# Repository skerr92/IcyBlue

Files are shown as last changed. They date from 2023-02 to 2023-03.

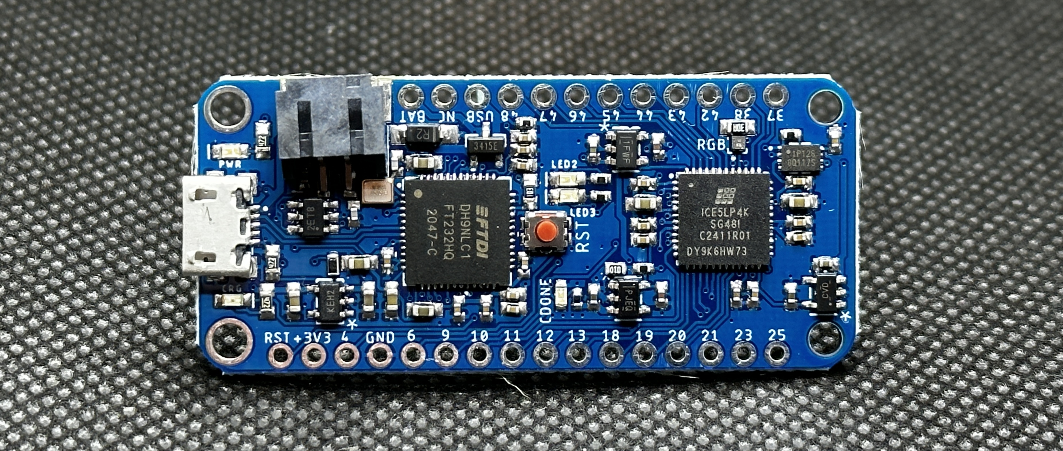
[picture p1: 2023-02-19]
Images/IMG_0353.jpg

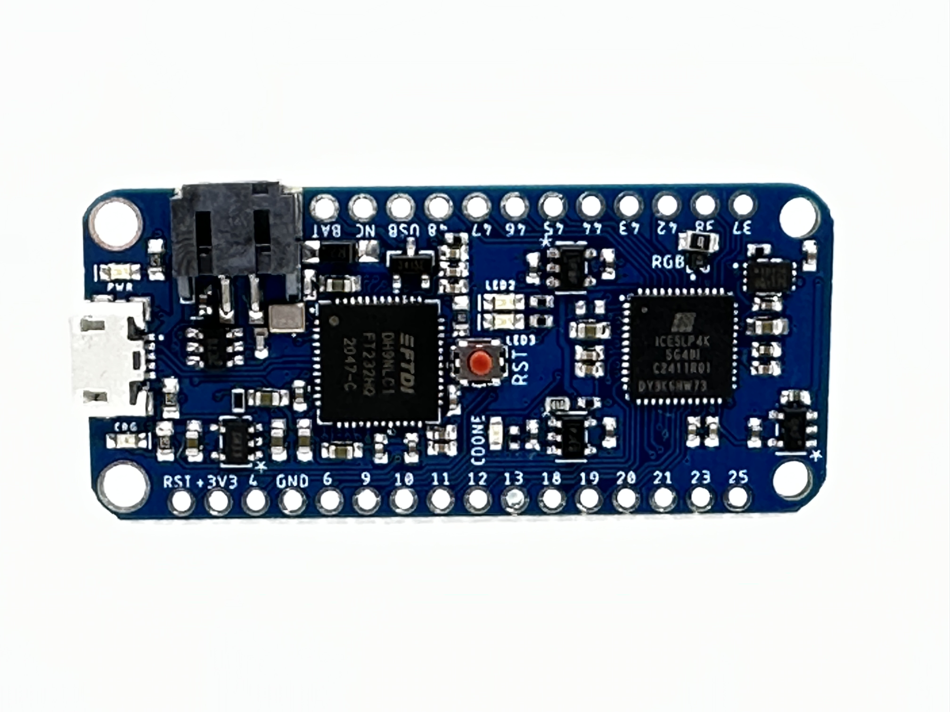
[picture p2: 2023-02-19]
Images/IMG_0367.JPG

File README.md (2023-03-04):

# IcyBlue Feather FPGA Development Board

<image src="https://github.com/skerr92/IcyBlue/blob/main/Images/IMG_0353.jpg">

Welcome to the home of the IcyBlue Feather, an FPGA based development board designed to be integrated into the Adafruit Feather ecosystem of Feathers and Feather Wings.

The goal of this repository is to be the single source of truth for the IcyBlue Feather. Containing all the relevant articles including images, schematics, usage examples, board files, and other important documentation.

Questions? Email [hello@oakdev.tech](mailto:hello@oakdev.tech)

### Documentation ###

All documentation can be found under the [Documentation](https://github.com/skerr92/IcyBlue/tree/main/Documentation) directory of this repository. This will include data sheets, usage guides, application notes, errata, and other important documents.

Documentation quick links:
* Data sheet: [IcyBlue Overview Data Sheet](https://github.com/skerr92/IcyBlue/blob/main/Documentation/IcyBlue%20Feather%20Datasheet%20rev1a.pdf)
* Board files: [EagleCAD Board Files](https://github.com/skerr92/IcyBlue/blob/main/Documentation/Lattice%20FPGA%20standard%20feather%20wing.brd)
* Schematic files: [EagleCAD Schematic Files](https://github.com/skerr92/IcyBlue/blob/main/Documentation/Lattice%20FPGA%20standard%20feather%20wing.sch)

### Schematic ###

Represented below is the Rev 1a schematic. This is the current production schematic for the IcyBlue Feather. If major hardware changes are added, additional labeled schematic images can be found here and in the [documentation directory](https://github.com/skerr92/IcyBlue/tree/main/Documentation).

<image src="https://github.com/skerr92/IcyBlue/blob/main/Images/IcyBlue%20Feather%20Schematic.png">

### Usage Examples ###

All usage examples including the RGB sequence example that ships with the board can be found in the [examples repository](https://github.com/skerr92/ice5lp4k_examples).

Examples Quick Links:
* [RGB Blink](https://github.com/skerr92/ice5lp4k_examples/tree/master/leds)
* [DSP Example](https://github.com/skerr92/ice5lp4k_examples/tree/master/dsp)

### Errata ###

Any Errate for the IcyBlue Feather will be linked below with the specific dates and errata version.

### Additional Information ###

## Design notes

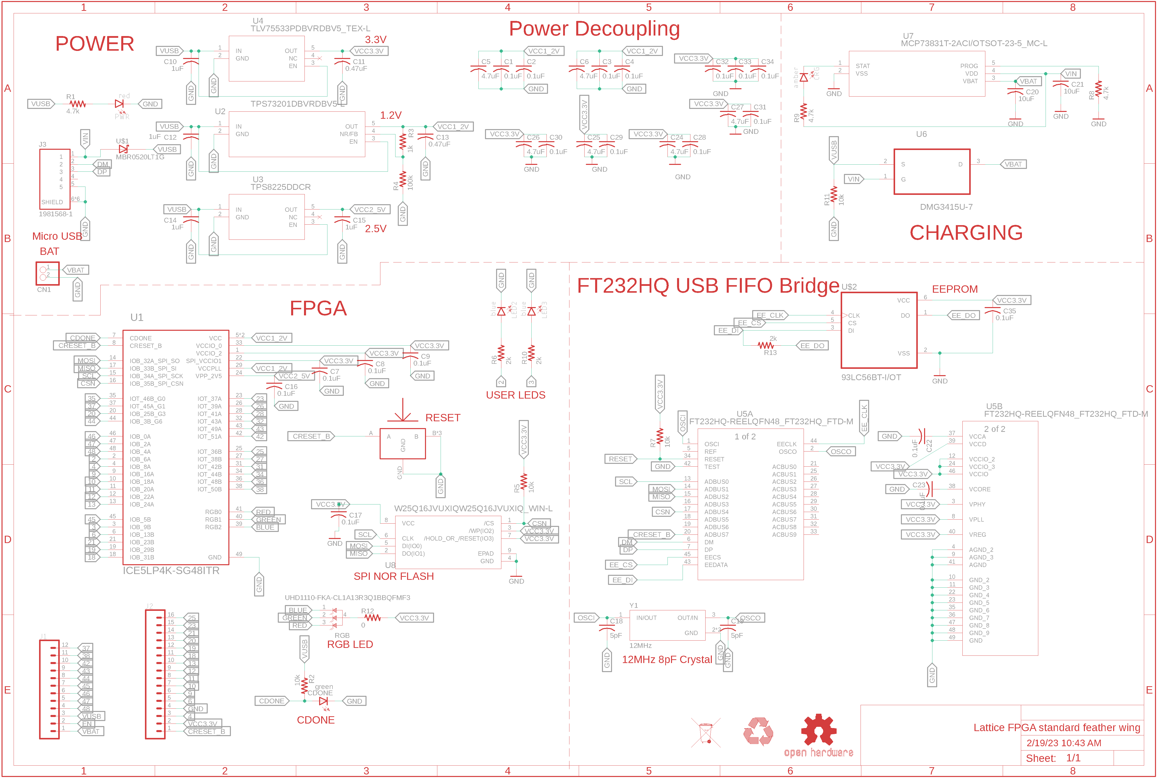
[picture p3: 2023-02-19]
Images/IcyBlue Feather Schematic.png

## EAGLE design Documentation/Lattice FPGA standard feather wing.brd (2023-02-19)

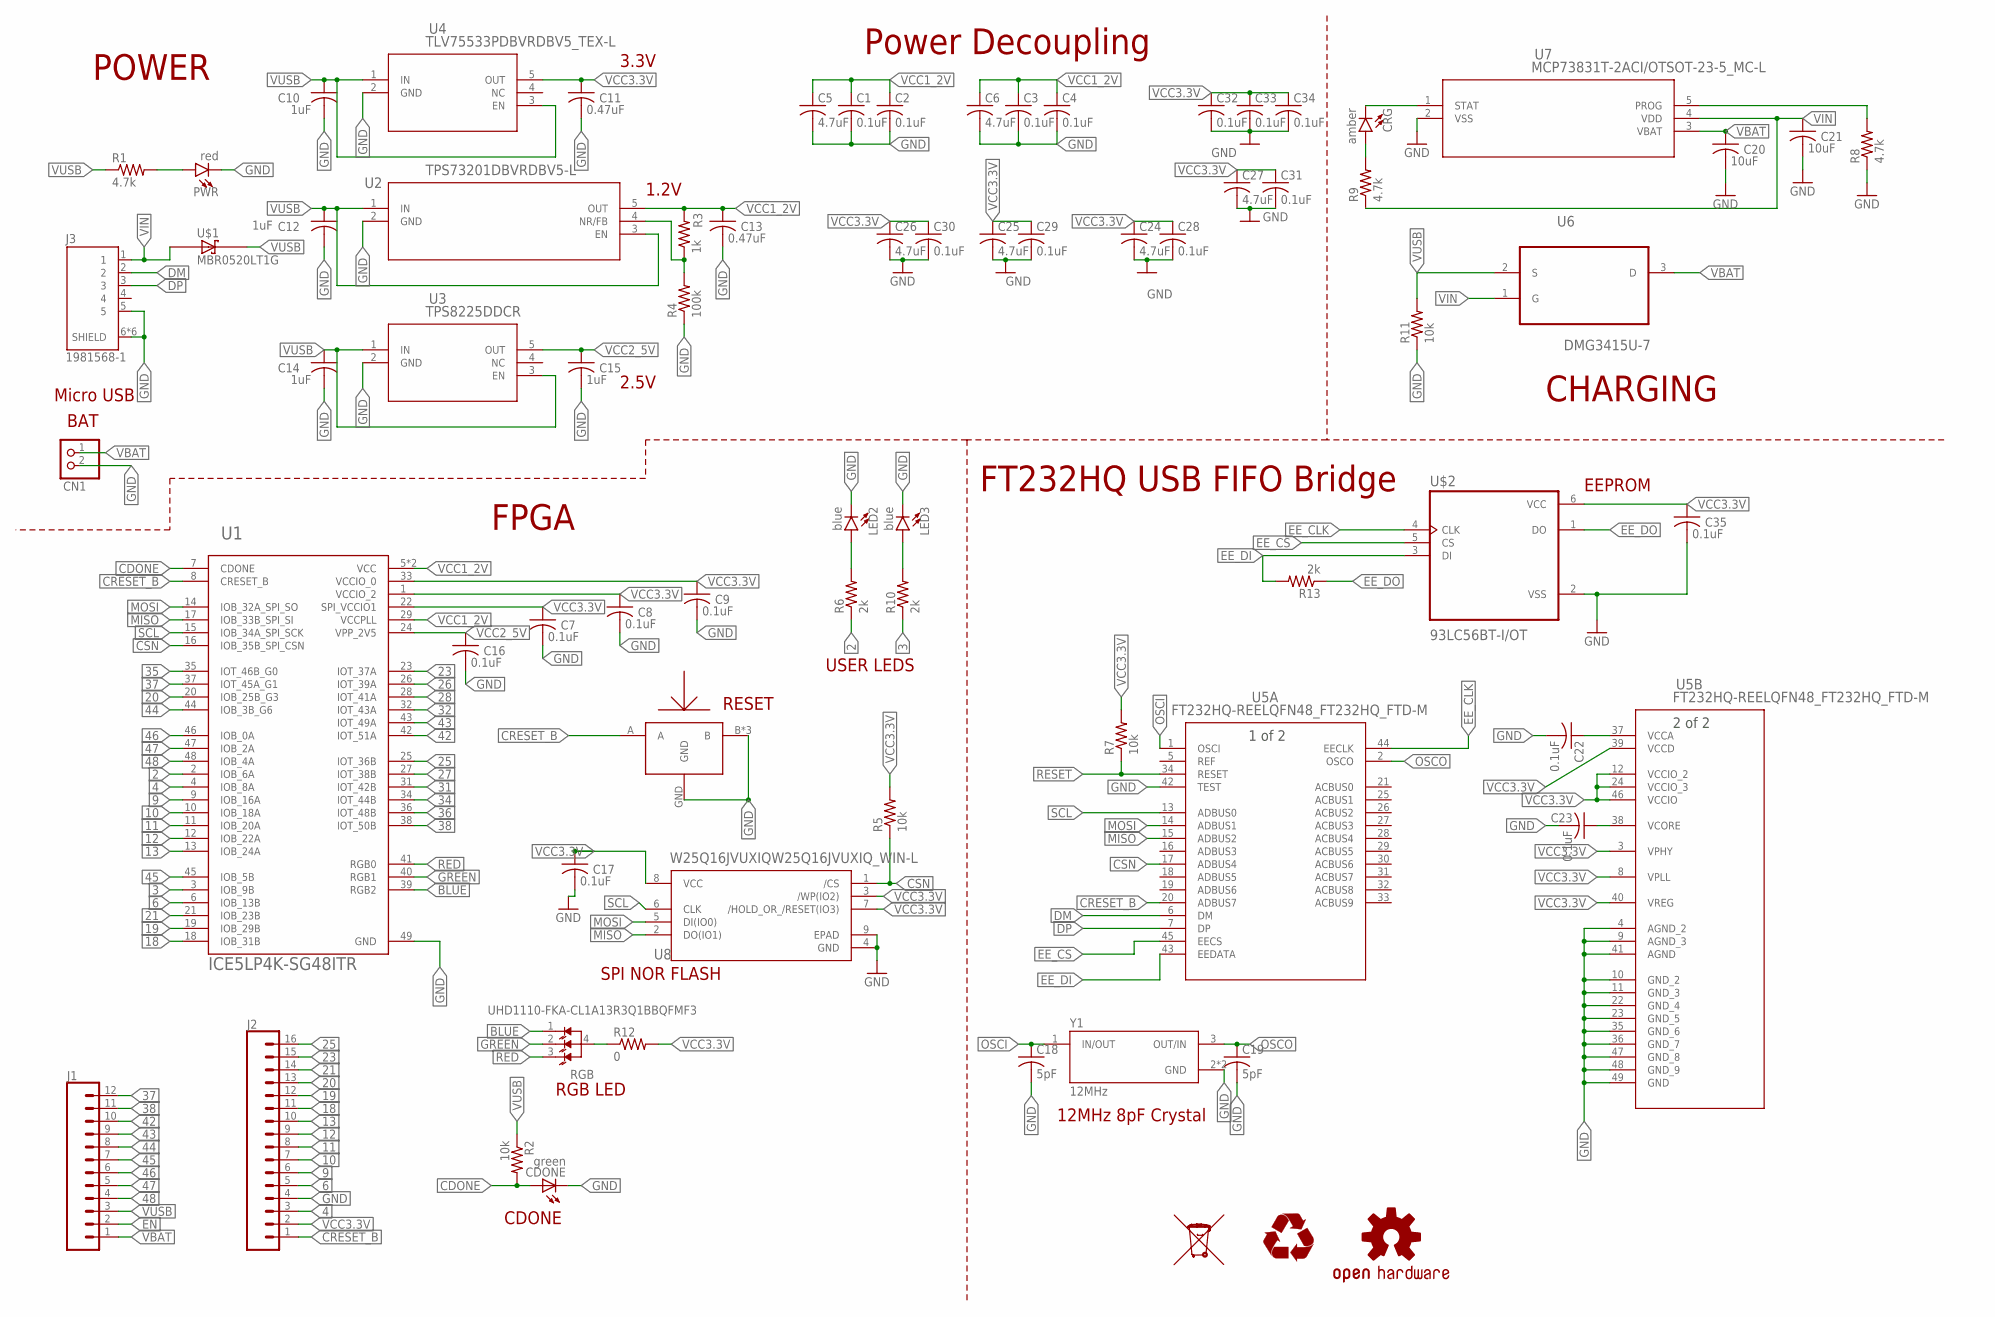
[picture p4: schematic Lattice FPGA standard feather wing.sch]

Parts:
C1, C2, C3, C4, C7, C8, C9, C16, C17, C22, C23, C28, C29, C30, C31, C32, C33, C34, C35: 0.1uF; C0402
C5, C6, C24, C25, C26, C27: 4.7uF; C0603
C10, C12, C14, C15: 1uF; C0402
C11, C13: 0.47uF; C0402
C18, C19: 5pF; C0402
C20, C21: 10uF; C0603
CDONE: green; CHIP-LED0603
CN1: JST_2PIN-SMT-RA; JST-PH-2-SMT-RA
CRG: amber; LED-0603
J1: CONN_12NO_SILK; 1X12_NO_SILK
J2: CONN_161X16_NO_SILK; 1X16_NO_SILK
J3: 1981568-1; TE_1981568-1
LED2, LED3: blue; LED-0603
LOGO1: OSHW-LOGOS; OSHW-LOGO-S
PWR: red; LED-0603
R1, R8, R9: 4.7k; R0603
R2, R5, R11: 10k; R0402
R3: 1k; R0402
R4: 100k; R0402
R6, R10, R13: 2k; R0402
R7: 10k; R0603
R12: 0; R0603
RGB: UHD1110-FKA-CL1A13R3Q1BBQFMF3; LED_UHD1110-FKA-CL1A13R3Q1BBQFMF3
U1: ICE5LP4K-SG48ITR; QFN50P700X700X100-49N
U2: TPS73201DBVRDBV5-L; DBV5-L
U3: TPS8225DDCR; DBV5_TEX-L
U4: TLV75533PDBVRDBV5_TEX-L; DBV5_TEX-L
U5: FT232HQ-REELQFN48_FT232HQ_FTD-M; QFN48_FT232HQ_FTD-M
U6: DMG3415U-7; SOT95P240X105-3N
U7: MCP73831T-2ACI/OTSOT-23-5_MC-L; SOT-23-5_MC-L
U8: W25Q16JVUXIQW25Q16JVUXIQ_WIN-L; W25Q16JVUXIQ_WIN-L
U$1: MBR0520LT1G; SOD3716X117(SOD-123)
U$2: 93LC56BT-I/OT; SOT95P280X145-6N
U$3: SOF-232HST; 3.3X2.9
Y1: 12MHz; XTAL_ECS-480-10-37-JTN-TR

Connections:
2: R6.1, U1.2 (IOB_6A)
3: R10.1, U1.3 (IOB_9B)
4: J2.3, U1.4 (IOB_8A)
6: J2.5, U1.6 (IOB_13B)
9: J2.6, U1.9 (IOB_16A)
10: J2.7, U1.10 (IOB_18A)
11: J2.8, U1.11 (IOB_20A)
12: J2.9, U1.12 (IOB_22A)
13: J2.10, U1.13 (IOB_24A)
18: J2.11, U1.18 (IOB_31B)
19: J2.12, U1.19 (IOB_29B)
20: J2.13, U1.20 (IOB_25B_G3)
21: J2.14, U1.21 (IOB_23B)
23: J2.15, U1.23 (IOT_37A)
25: J2.16, U1.25 (IOT_36B)
26: U1.26 (IOT_39A)
27: U1.27 (IOT_38B)
28: U1.28 (IOT_41A)
31: U1.31 (IOT_42B)
32: U1.32 (IOT_43A)
34: U1.34 (IOT_44B)
35: U1.35 (IOT_46B_G0)
36: U1.36 (IOT_48B)
37: J1.12, U1.37 (IOT_45A_G1)
38: J1.11, U1.38 (IOT_50B)
42: J1.10, U1.42 (IOT_51A)
43: J1.9, U1.43 (IOT_49A)
44: J1.8, U1.44 (IOB_3B_G6)
45: J1.7, U1.45 (IOB_5B)
46: J1.6, U1.46 (IOB_0A)
47: J1.5, U1.47 (IOB_2A)
48: J1.4, U1.48 (IOB_4A)
BLUE: RGB.1 (BLUE), U1.39 (RGB2)
CDONE: CDONE.A, R2.2, U1.7 (CDONE)
CRESET_B: J2.1, U1.8 (CRESET_B), U5.20 (ADBUS7), U$3.A
CSN: R5.1, U1.16 (IOB_35B_SPI_CSN), U5.17 (ADBUS4), U8.1 (/CS)
DM: J3.2, U5.6 (DM)
DP: J3.3, U5.7 (DP)
EE_CLK: U5.44 (EECLK), U$2.4 (CLK)
EE_CS: U5.45 (EECS), U$2.5 (CS)
EE_DI: R13.2, U5.43 (EEDATA), U$2.3 (DI)
EE_DO: R13.1, U$2.1 (DO)
EN: J1.2
GND: C1.2, C2.2, C3.2, C4.2, C5.2, C6.2, C7.2, C8.2, C9.2, C10.2, C11.2, C12.2, C13.2, C14.2, C15.2, C16.2, C17.2, C18.2, C19.2, C20.2, C21.2, C22.2, C23.2, C24.2, C25.2, C26.2, C27.2, C28.2, C29.2, C30.2, C31.2, C32.2, C33.2, C34.2, C35.2, CDONE.C, CN1.2 (1), J2.4, J3.5, J3.6 (SHIELD), J3.7 (SHIELD), J3.8 (SHIELD), J3.9 (SHIELD), J3.10 (SHIELD), J3.11 (SHIELD), LED2.C, LED3.C, PWR.C, R4.1, R8.1, R11.1, U1.49 (GND), U2.2 (GND), U3.2 (GND), U4.2 (GND), U5.4 (AGND_2), U5.9 (AGND_3), U5.10 (GND_2), U5.11 (GND_3), U5.22 (GND_4), U5.23 (GND_5), U5.35 (GND_6), U5.36 (GND_7), U5.41 (AGND), U5.42 (TEST), U5.47 (GND_8), U5.48 (GND_9), U5.49 (GND), U7.2 (VSS), U8.4 (GND), U8.9 (EPAD), U$2.2 (VSS), U$3.B, U$3.B2 (B), U$3.B3 (B), U$3.GND, Y1.2 (GND), Y1.4 (GND)
GREEN: RGB.2 (GREEN), U1.40 (RGB1)
MISO: U1.17 (IOB_33B_SPI_SI), U5.15 (ADBUS2), U8.2 (DO(IO1))
MOSI: U1.14 (IOB_32A_SPI_SO), U5.14 (ADBUS1), U8.5 (DI(IO0))
unnamed: R3.1, R4.2, U2.4 (NR/FB)
unnamed: R8.2, U7.5 (PROG)
unnamed: C23.1, U5.38 (VCORE)
unnamed: CRG.C, U7.1 (STAT)
unnamed: CRG.A, R9.2
unnamed: R12.1, RGB.4 (ANODE)
unnamed: PWR.A, R1.2
unnamed: C22.1, U5.37 (VCCA)
unnamed: LED2.A, R6.2
unnamed: LED3.A, R10.2
OSCI: C18.1, U5.1 (OSCI), Y1.1 (IN/OUT)
OSCO: C19.1, U5.2 (OSCO), Y1.3 (OUT/IN)
RED: RGB.3 (RED), U1.41 (RGB0)
RESET: R7.1, U5.34 (RESET)
SCL: U1.15 (IOB_34A_SPI_SCK), U5.13 (ADBUS0), U8.6 (CLK)
VBAT: C20.1, CN1.1 (2), J1.1, U6.3 (D), U7.3 (VBAT)
VCC1_2V: C1.1, C2.1, C3.1, C4.1, C5.1, C6.1, C13.1, R3.2, U1.5 (VCC), U1.29 (VCCPLL), U1.30 (VCC), U2.5 (OUT)
VCC2_5V: C15.1, C16.1, U1.24 (VPP_2V5), U3.5 (OUT)
VCC3.3V: C7.1, C8.1, C9.1, C11.1, C17.1, C24.1, C25.1, C26.1, C27.1, C28.1, C29.1, C30.1, C31.1, C32.1, C33.1, C34.1, C35.1, J2.2, R5.2, R7.2, R12.2, U1.1 (VCCIO_2), U1.22 (SPI_VCCIO1), U1.33 (VCCIO_0), U4.5 (OUT), U5.3 (VPHY), U5.8 (VPLL), U5.12 (VCCIO_2), U5.24 (VCCIO_3), U5.39 (VCCD), U5.40 (VREG), U5.46 (VCCIO), U8.3 (/WP(IO2)), U8.7 (/HOLD_OR_/RESET(IO3)), U8.8 (VCC), U$2.6 (VCC)
VIN: C21.1, J3.1, R9.1, U6.1 (G), U7.4 (VDD), U$1.2 (A)
VUSB: C10.1, C12.1, C14.1, J1.3, R1.1, R2.1, R11.2, U2.1 (IN), U2.3 (EN), U3.1 (IN), U3.3 (EN), U4.1 (IN), U4.3 (EN), U6.2 (S), U$1.1 (C)

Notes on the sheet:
SPI NOR FLASH
FPGA
POWER
BAT
CHARGING
EEPROM
FT232HQ USB FIFO Bridge
12MHz 8pF Crystal
RGB LED
CDONE
RESET
USER LEDS
1.2V
2.5V
3.3V
Power Decoupling
Micro USB

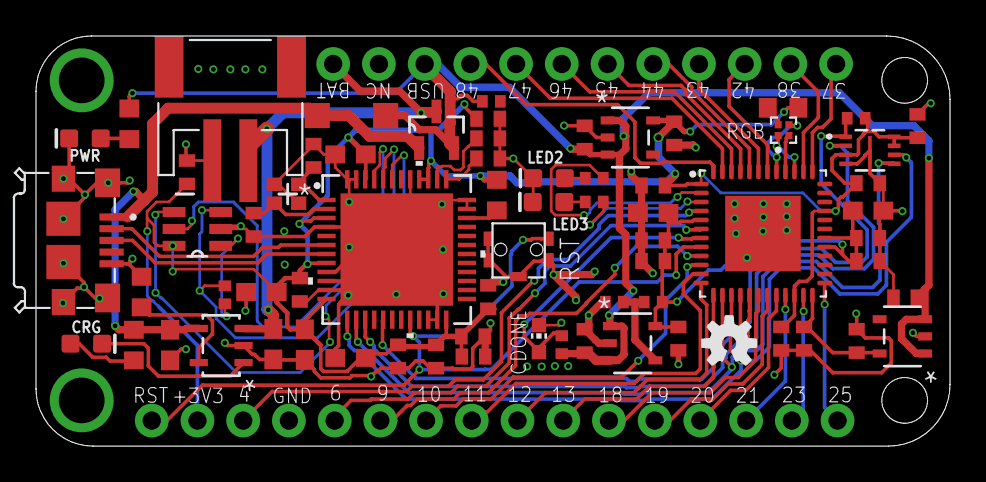
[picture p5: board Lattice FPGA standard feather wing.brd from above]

Board: 2 copper layers, 50.8 x 22.8 mm, 71 parts (0 on the bottom side), 59 nets.

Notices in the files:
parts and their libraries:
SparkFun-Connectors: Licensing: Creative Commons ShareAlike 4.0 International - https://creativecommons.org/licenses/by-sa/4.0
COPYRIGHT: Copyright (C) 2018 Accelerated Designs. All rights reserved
